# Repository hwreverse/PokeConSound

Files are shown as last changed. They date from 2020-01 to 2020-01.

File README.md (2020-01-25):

# PokeConSound
OPL / OPLL* / SID Soundcard Designs for Pocket Computers (ポケコン) (Sharp, Casio, TRS80-M100,...)

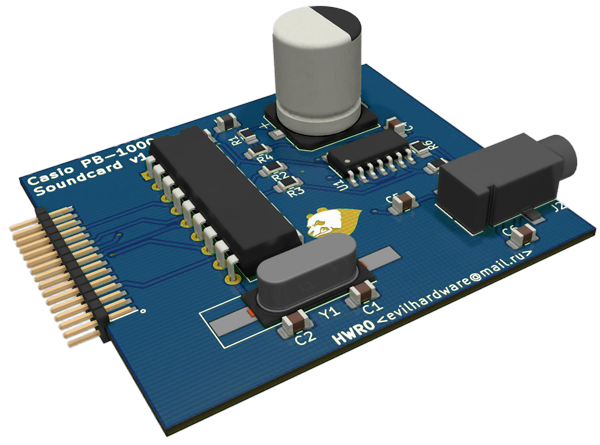
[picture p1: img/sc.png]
SoundCard


<a href="Orig.Designs/">Original Designs I modeled in KiCAD that gave the inspiration</a>

As soon as the function of the original designs is validated (waiting for the Chinese New Year to finish to order the boards..),<br>
I will rework the designs to add buffering, power supply, a stereo system, bigger chips, you name it !

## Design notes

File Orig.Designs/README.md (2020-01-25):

# Original Soundcard Designs

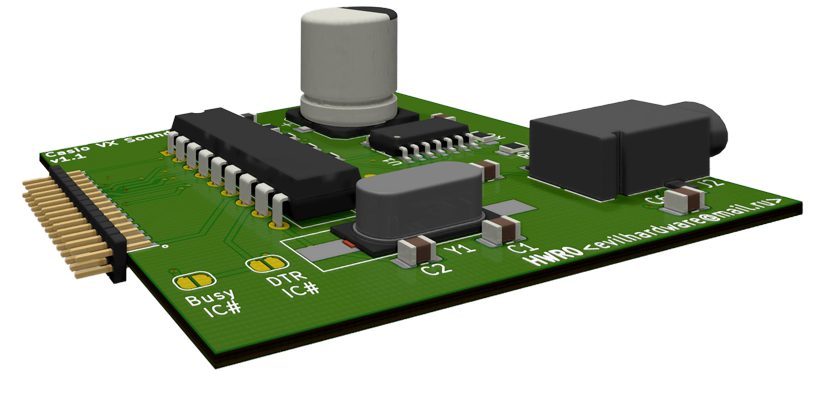
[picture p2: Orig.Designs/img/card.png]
SoundCard


Following Soundcard designs were found on the Internet Archive (Miyura, 2010)
and put into KiCAD by yours truly with very little modifications.

<a href="CASIO%20PB-1000%20YM2413%20Soundcard/">OPLL Soundcard for Casio PB-1000</a>

<a href="CASIO%20VX4%20YM2413%20Soundcard%20v1.1/">OPLL Soundcard for Casio VX-3,4,Z-1</a>

Footprints for RLC are 0805 (except for the one big capacitor).<br>
Integrated circuits are in DIP or SOIC footprint, to be more kind to people without killer solder skills.<br>
All components except the YM2413B can be sourced from LCSC.com. I bought my YM2413Bs on Ebay<br>
**Make sure that PCBs are fabricated in 0.8mm thickness, otherwise you couldn't fit the PCB in the 2x15 1.27mm Casio Interface Connector**<br>

__**Positive points:**__ 
- elegant and simple design
- no extra power supply needed

__**Negative Points:**__
- YM2413B Chip directly connected to Casio System Bus without buffer (f... dangerous!)
- no extra power supply (will consume the Casio Batteries quite nicely IMHO)
- minimal Code Examples were provided for PB-1000 **but not for VX-4** (so figure it out yourself)

I will rework the designs as soon as I validate these (I'll order the PCBs after Chinese New Year)

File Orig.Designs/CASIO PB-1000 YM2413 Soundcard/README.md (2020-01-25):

# Casio PB-1000 OPLL Soundcard v1.0

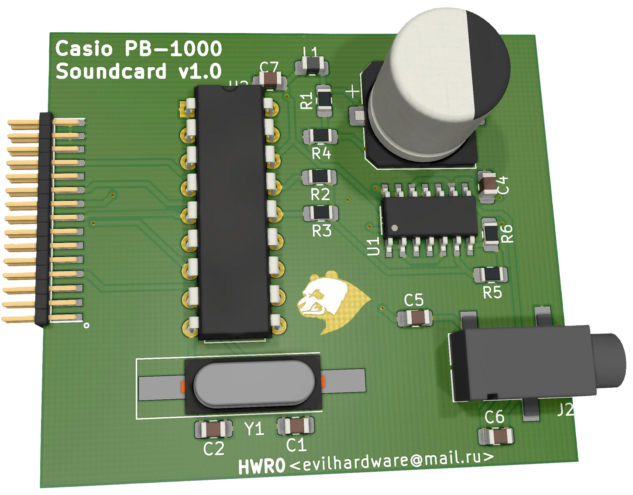
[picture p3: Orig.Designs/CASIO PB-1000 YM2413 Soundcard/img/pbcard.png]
Soundcard


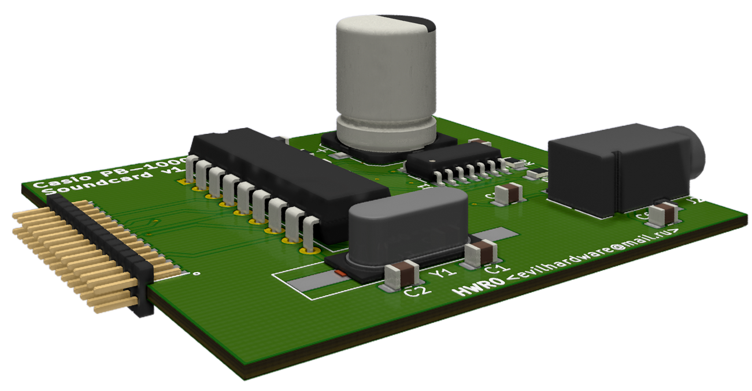
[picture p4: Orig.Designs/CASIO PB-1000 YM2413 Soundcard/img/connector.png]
Connector


**Make sure that PCBs are fabricated in 0.8mm thickness, otherwise you couldn't fit the PCB in the 2x15 1.27mm Casio Interface Connector**

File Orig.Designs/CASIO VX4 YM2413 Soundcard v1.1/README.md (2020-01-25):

# Casio VX3,VX4 + Z-1 Soundcard

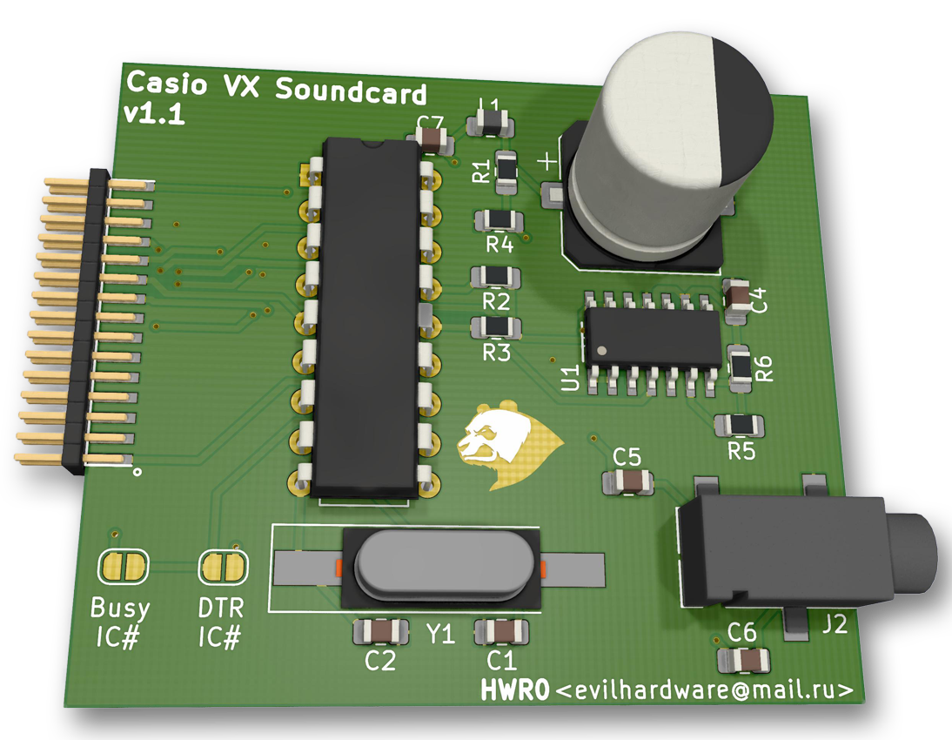
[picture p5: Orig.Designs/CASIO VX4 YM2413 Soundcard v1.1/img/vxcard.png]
VXCard


Connector

**Make sure that PCBs are fabricated in 0.8mm thickness, otherwise you couldn't fit the PCB in the 2x15 1.27mm Casio Interface Connector**

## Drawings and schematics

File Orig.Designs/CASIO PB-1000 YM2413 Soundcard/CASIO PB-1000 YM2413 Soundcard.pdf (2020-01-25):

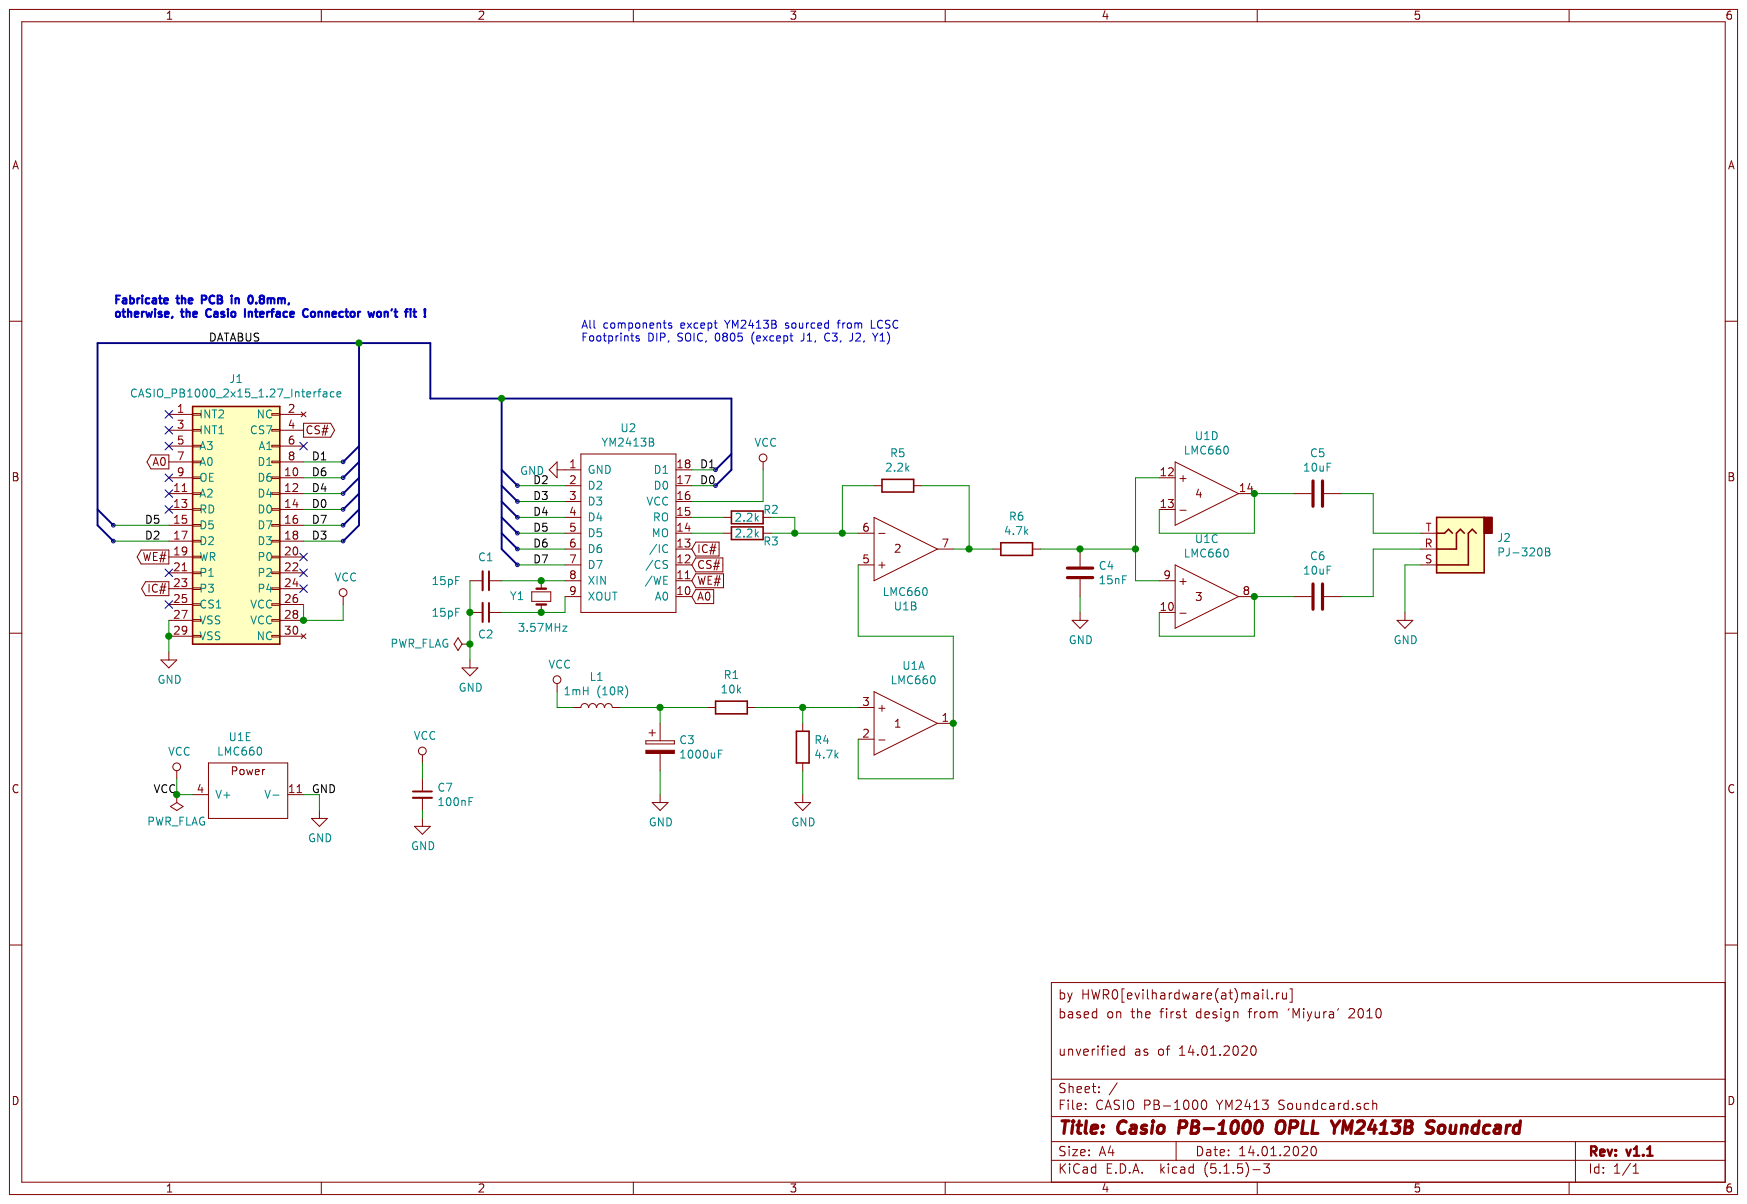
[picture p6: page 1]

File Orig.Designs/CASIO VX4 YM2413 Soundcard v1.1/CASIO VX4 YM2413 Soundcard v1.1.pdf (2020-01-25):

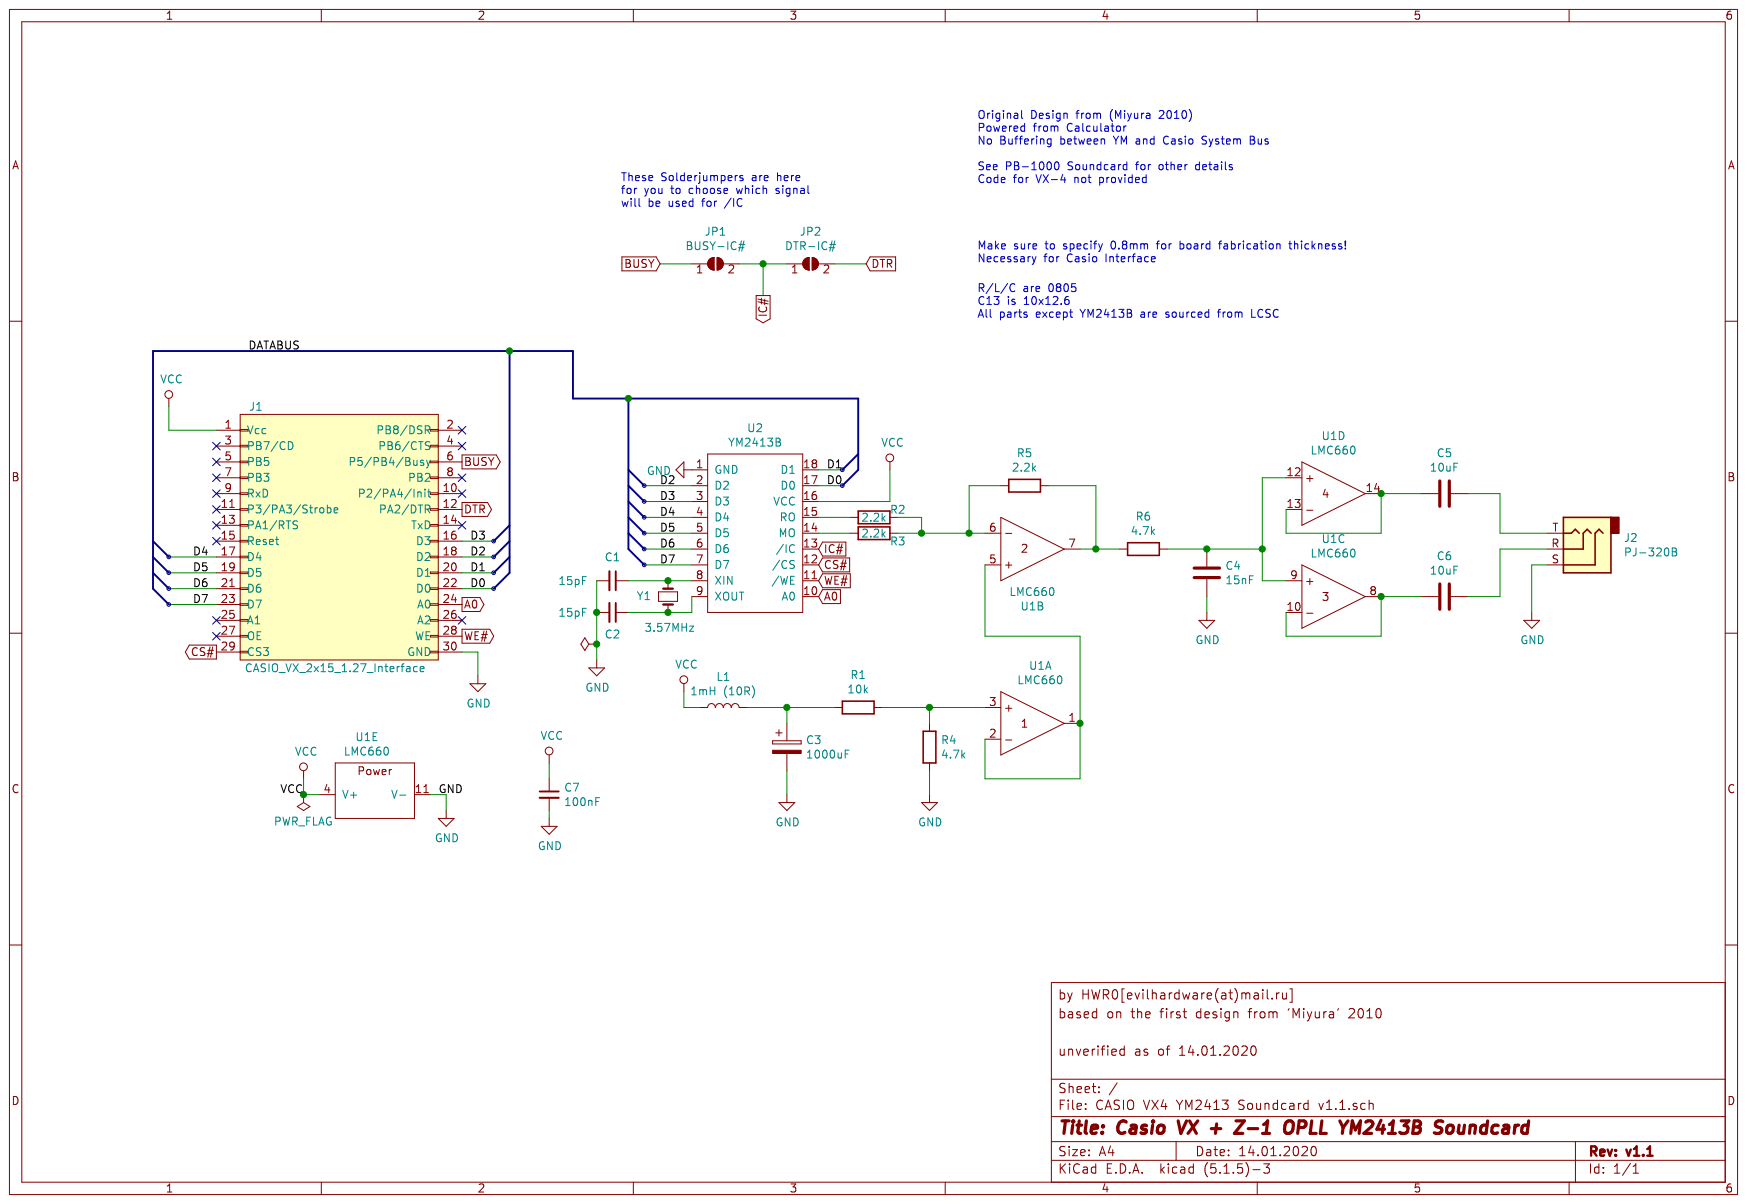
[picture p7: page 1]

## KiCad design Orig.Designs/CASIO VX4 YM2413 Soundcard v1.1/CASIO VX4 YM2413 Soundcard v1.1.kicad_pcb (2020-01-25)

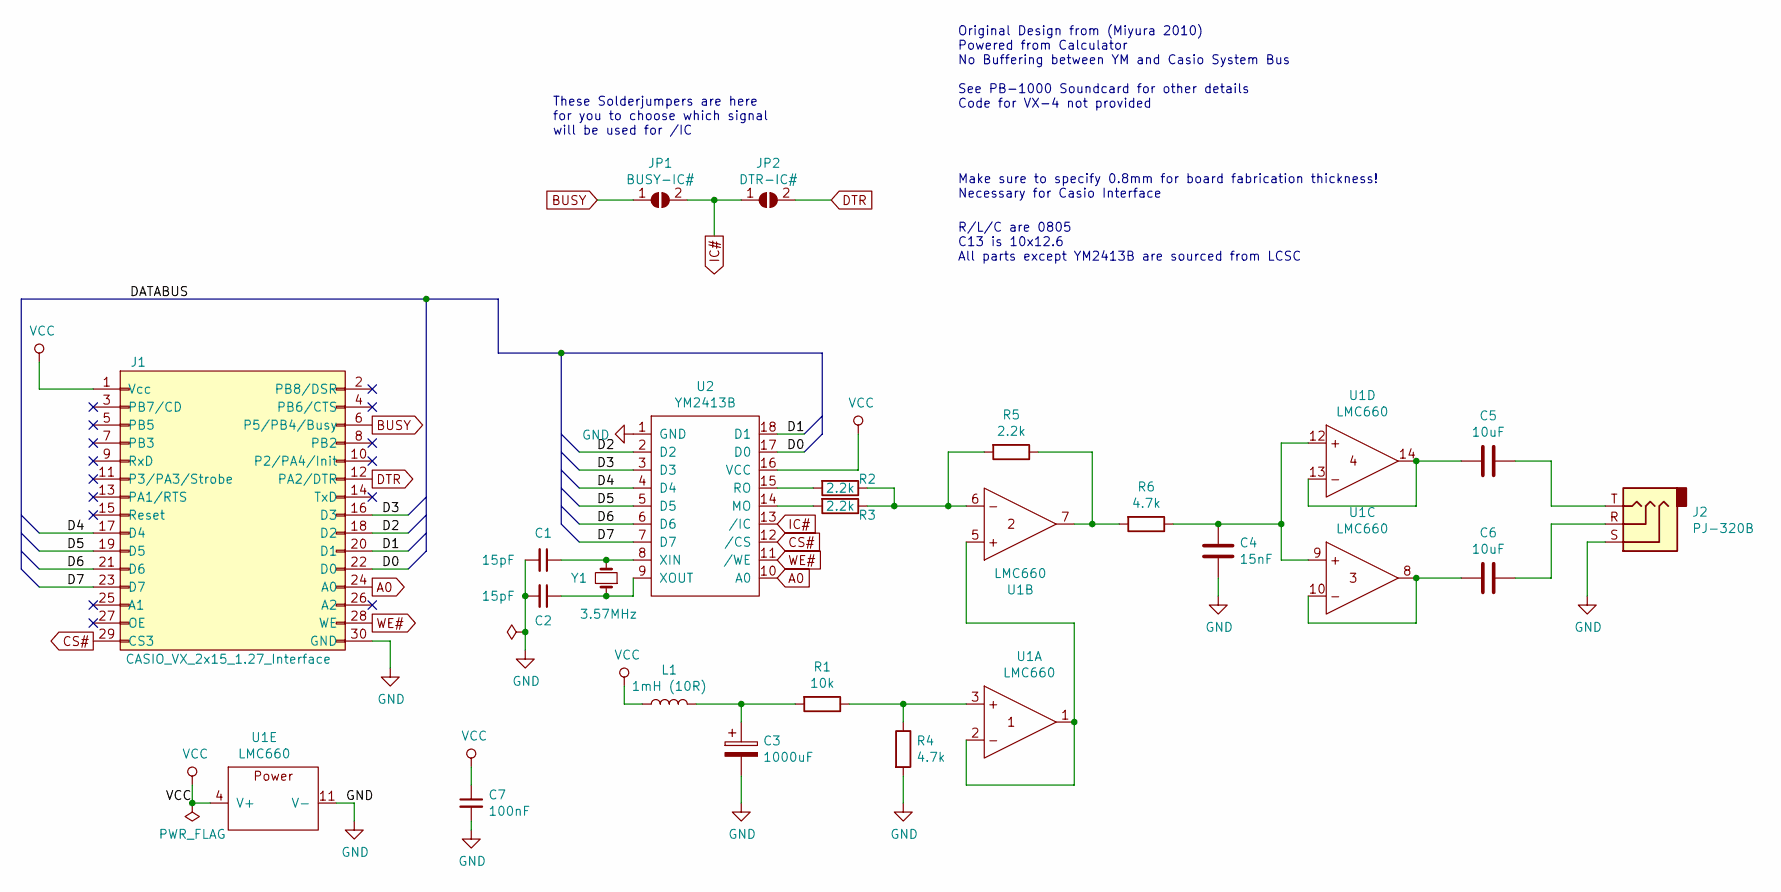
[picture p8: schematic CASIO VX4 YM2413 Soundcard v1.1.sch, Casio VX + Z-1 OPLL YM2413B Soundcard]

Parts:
C1, C2: 15pF; C_0805_2012Metric_Pad1.15x1.40mm_HandSolder
C3: 1000uF; CP_Elec_10x12.6
C4: 15nF; C_0805_2012Metric_Pad1.15x1.40mm_HandSolder
C5, C6: 10uF; C_0805_2012Metric_Pad1.15x1.40mm_HandSolder
C7: 100nF; C_0805_2012Metric_Pad1.15x1.40mm_HandSolder
J1: CASIO_VX_2x15_1.27_Interface; Connector_Casio_2x15_1.27_SYSBUS
J2: PJ-320B; BOOMELE_PJ-320B
JP1: BUSY-IC#; SolderJumper-2_P1.3mm_Open_RoundedPad1.0x1.5mm
JP2: DTR-IC#; SolderJumper-2_P1.3mm_Open_RoundedPad1.0x1.5mm
L1: 1mH (10R); L_0805_2012Metric_Pad1.15x1.40mm_HandSolder
R1: 10k; R_0805_2012Metric_Pad1.15x1.40mm_HandSolder
R2, R3, R5: 2.2k; R_0805_2012Metric_Pad1.15x1.40mm_HandSolder
R4, R6: 4.7k; R_0805_2012Metric_Pad1.15x1.40mm_HandSolder
U1: LMC660; SOIC127P600X175-14N
U2: YM2413B; DIP-18_W7.62mm
Y1: 3.57MHz; Crystal_SMD_HC49-SD_HandSoldering

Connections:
/D0: J1.22 (D0), U2.17 (D0)
/D1: J1.20 (D1), U2.18 (D1)
/D2: J1.18 (D2), U2.2 (D2)
/D3: J1.16 (D3), U2.3 (D3)
/D4: J1.17 (D4), U2.4 (D4)
/D5: J1.19 (D5), U2.5 (D5)
/D6: J1.21 (D6), U2.6 (D6)
/D7: J1.23 (D7), U2.7 (D7)
A0: J1.24 (A0), U2.10 (A0)
BUSY: J1.6 (P5/PB4/Busy), JP1.1 (A)
CS#: J1.29 (CS3), U2.12 (/CS)
DTR: J1.12 (PA2/DTR), JP2.2 (B)
GND: C1.2, C2.2, C3.2, C4.2, C7.2, J1.30 (GND), J2.S, R4.2, U1.11 (V-), U2.1 (GND)
IC#: JP1.2 (B), JP2.1 (A), U2.13 (/IC)
unnamed: C1.1, U2.8 (XIN), Y1.2
unnamed: C2.1, U2.9 (XOUT), Y1.1
unnamed: C3.1, L1.2, R1.2
unnamed: C4.1, R6.1, U1.9, U1.12
unnamed: C5.1, U1.13, U1.14
unnamed: C5.2, J2.T
unnamed: C6.1, U1.8, U1.10
unnamed: C6.2, J2.R
unnamed: R1.1, R4.1, U1.3
unnamed: R2.1, R3.1, R5.2, U1.6
unnamed: R2.2, U2.15 (RO)
unnamed: R3.2, U2.14 (MO)
unnamed: R5.1, R6.2, U1.7
unnamed: U1.1, U1.2, U1.5
VCC: C7.1, J1.1 (Vcc), L1.1, U1.4 (V+), U2.16 (VCC)
WE#: J1.28 (WE), U2.11 (/WE)

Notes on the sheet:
Make sure to specify 0.8mm for board fabrication thickness! Necessary for Casio Interface
R/L/C are 0805 C13 is 10x12.6 All parts except YM2413B are sourced from LCSC
Original Design from (Miyura 2010) Powered from Calculator No Buffering between YM and Casio System Bus See PB-1000 Soundcard for other details Code for VX-4 not provided
These Solderjumpers are here for you to choose which signal will be used for /IC

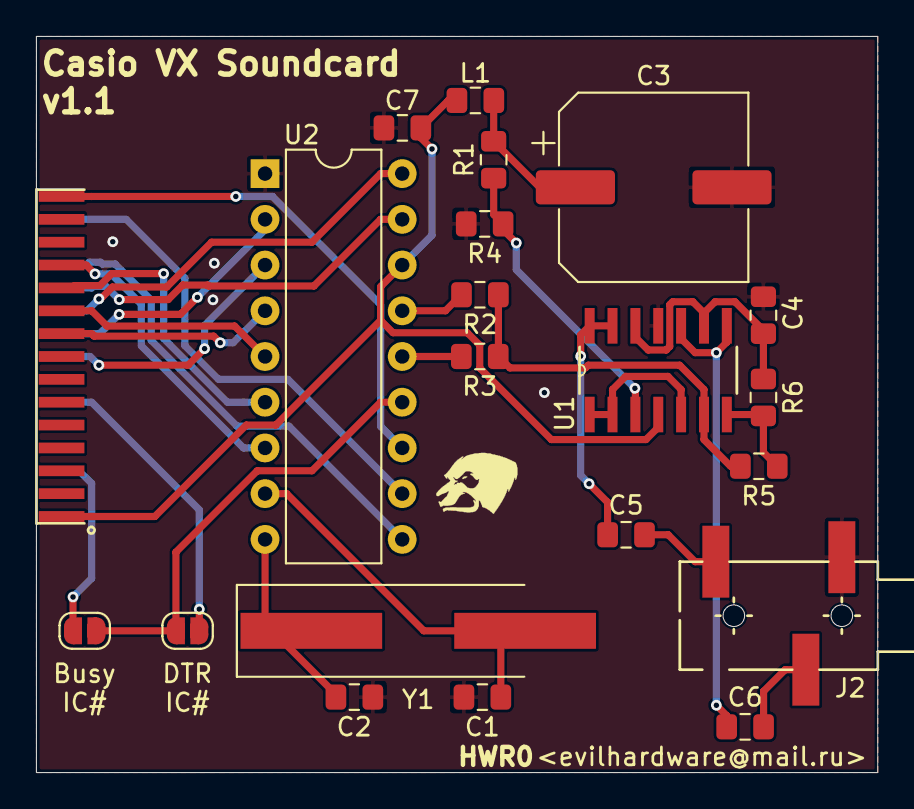
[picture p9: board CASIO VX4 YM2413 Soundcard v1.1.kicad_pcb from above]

Board: 2 copper layers, 46.7 x 40.9 mm, 21 parts (0 on the bottom side), 30 nets.
